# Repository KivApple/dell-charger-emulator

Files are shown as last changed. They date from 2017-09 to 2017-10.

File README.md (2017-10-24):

# dell-charger-emulator
Emulator of original Dell charger using ATTINY85

Power adapter for Dell laptops contains IC to determine adapter capabilities (watts, voltage, current).
If you connect an unoriginal adapter, the laptop refuses to charge the battery.
This project allows to use the cheap and small microcontroller ATTINY85 for emulating the answers
of the original adapter to the requests of the laptop.

You can configure adapter settings in the file eeprom-data.hex. This file contains EEPROM data in Intel Hex format.
Format of Dell charger identification shown below:

| Offset | Length | Content | Description |
|---|---|---|---|
| 0 | 4 | DELL | Manufacturer identifier  |
| 4 | 4 | 00AC | Adapter type |
| 8 | 3 | 045 | Watts (45W) |
| 11 | 3 | 195 | Tenths of a volt (19.5V) |
| 14 | 3 | 023 | Tenths of amps (2.3A) |
| 17 | 23 | CN0CDF577243865Q27F2A05 | Serial number |
| 40 | 2 | 0x3D 0x94 | CRC-16/ARC (LSB first) |

The description may not be entirely accurate. I'll be glad if you clarify.

You can use Python utility dell-charger-data-editor.py to easily change this values.

You must flash the EEPROM data together with the program code. Later you can only re-write EEPROM.

**Warning: do not mask the weak power adapter to a more powerful one. This can lead to hardware damage.**

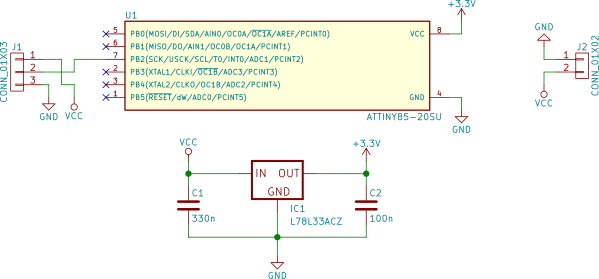
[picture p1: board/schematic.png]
Schematic


You need ATTINY25, ATTINY45 or ATTINY85 MCU (you may need to change compiler flags in Makefile) running at 8 MHz (the internal RC-oscillator is suitable, but if desired, you can use an external crystal - adjust the fuses accordingly). The Dell power adapter connector has three pins - GND, VOUT (19V) and ID. Connect the ID to the PB2 pin of the microcontroller. Also provide 3.3V power for MCU (you can use a simple linear regulator 78L33 to make the desired voltage from 19V).

## Reading and writing EEPROM

You can read and write EEPROM using dell-charger-data-editor.py (see console menu of this utility).

You need connect OneWire bus to any USB-UART adapter using simple schematic with diode:

    TXD --------|<|----*-------- ID
                       |
    RXD ----------------

    GND ------------------------ GND

**Warning: USB-UART adapter should use 3.3V or 5V logic levels. 12V levels will damage EEPROM IC.**

You can read by this utility both original EEPROM and emulated by AVR. You can write only emulated EEPROM.

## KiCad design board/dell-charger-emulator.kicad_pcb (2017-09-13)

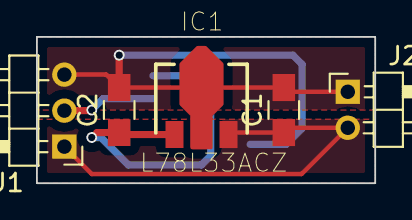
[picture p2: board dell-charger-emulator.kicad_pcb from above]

Board: 2 copper layers, 18.8 x 8.1 mm, 6 parts (1 on the bottom side), 4 nets.

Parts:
C1: 330n; C_0805_HandSoldering
C2: 100n; C_0805_HandSoldering
IC1: L78L33ACZ; SOT-89-3
J1: CONN_01X03; Pin_Header_Angled_1x03_Pitch2.00mm
J2: CONN_01X02; Pin_Header_Angled_1x02_Pitch2.00mm
U1: ATTINY85-20SU; SOIC-8_3.9x4.9mm_Pitch1.27mm

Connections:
+3V3: C2.1, IC1.1, U1.8
GND: C1.2, C2.2, IC1.2, J1.3, J2.1, U1.4
unnamed: J1.2, U1.7
VCC: C1.1, IC1.3, J1.1, J2.2

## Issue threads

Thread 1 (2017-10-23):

No Thorough Hardware Instructions

alxpettit, 2017-10-23:
It would be useful to see the wiring schematic you used for this project. Perhaps you could add it to README.md?

Edit: Also, I'm confused. Does this let us also program cheap Ebay knock offs to look like "genuine" Dell chargers? Your README.md instructs the user to connect to it to the "OneWire bus", but it's not exactly clear what that means. Some clear schematics of the use cases -- both when programming the chip, and when putting it into circuit, would be useful.

Edit 2: also, would this work on an 'duino? Lots more people have 'duinos, instead of Tiny85s lying around. I'd like to try this project before my Tiny85s and dev boards arrive.

KivApple, 2017-10-24:
I have wrote in README.md:

> You need ATTINY25, ATTINY45 or ATTINY85 MCU (you may need to change compiler flags in Makefile) running at 8 MHz (the internal RC-oscillator is suitable, but if desired, you can use an external crystal - adjust the fuses accordingly). The Dell power adapter connector has three pins - GND, VOUT (19V) and ID. Connect the ID to the PB2 pin of the microcontroller. Also provide 3.3V power for MCU (you can use a simple linear regulator 78L33 to make the desired voltage from 19V).

The connection scheme is present in the board directory in KiCad format, there is also a proposed printed circuit board. But since you ask, I added a picture to README.md.

The Python script is able to flash EEPROM through the 1wire only of the emulator on the AVR, it is not able to flash the real DS2502, because, first, it has an add-only memory, and secondly, it needs to supply the increased voltage at the right moment for programming. However, a script in Python is able to read the contents of both the emulator and the real memory chip. Of course, for the emulator to respond to the 1wire protocol, you need to download my firmware into it via any AVR programmer (for example, USBASP).

Perhaps this scheme will work on "large" microcontrollers like ATMEGA328 (used in many Arduino). In principle, all that the program needs is one external interrupt (INT0 usually) and one timer with one comparison channel. And a couple of kilobytes of ROM. However, AVR microcontrollers have some differences and most likely you will need a small edit of the sources to make everything work.

I used ATTINY, because in this way I could make a PCB of the smallest size and fit it into the plug of the power adapter. In addition, the ATTINY85 chip is cheaper than the ATMEGA328 chip.

alxpettit, 2017-10-28:
I've gotten arduino nano clones for as little as $3 per unit -- they are surprisingly cheap. I agree that they are definitely overkill for this project, and certainly wouldn't give you a great form factor, but general purpose programmable chips are overkill for a lot of their applications. I'd argue that the point of a programmable chip is to do lots of possible functions, some simple, and some really complex.

It only makes economical sense to make programmable chips that do simple things, because the less _unique_ things industry has to make, the cheaper it is to make them -- we can optimize via creating generic solutions and retooling them to every possible use case.

It's also good as a way to test an idea before you invest in more specialized hardware, I think. But Tiny85s are so cheap on Ebay, that I bought a couple of them just for testing on this project. I just think other people might not be willing to spend money experimentally, though -- and it's a shame, if they're barred from trying this project out because they don't have the hardware.

In my case, I can't really imagine a use for Tiny85s besides weird little things like this -- or just getting an LED to blink with a specific pattern, or doing some very very simple logic control... usually when I'm working with hardware, I'm working with fairly advanced robotics. (And furthermore, I'm normally a high level software gal. System administration, Python, that sort of thing. I rarely end up doing manual memory management, and the most low level thing I do is C++ coding on Arduinos, usually.)

So firmware-level things like this are out of my usual scope. I freely admit I could be talking out of my excretion hole here. And I totally respect if you don't want to put the effort in to translate it over to an arduino. :P

Oh, and sorry I didn't recognize the KiCad. I've never used it in my life before. The closest I've ever come is using a perfboard. Thank you for adding the PNG schematic!

TehseenHasan, 2020-06-27:
I made a complete tutorial: https://github.com/KivApple/dell-charger-emulator/issues/4#issuecomment-650623879

KivApple, 2020-06-27:
@alxpettit If anyone wants to add support for different AVR MCUs (such as ATMEGA328 which is used in Arduino Uno) feel free to create a pull request. You can easily upload plain C code into Arduino board. It is not required to use Arduino libraries when you are programming Arduino so you can write code which will be compatible both with ATTINY85 and ATMEGA328 (with few #ifdef's).

lgolebio, 2022-04-16:
Hi, I'm totaly noob at electronics and arduino. I have one question. Why it is not possbile to upload code to Digispark Attiny85 through built in USB port ?

Closed 2017-10-28.

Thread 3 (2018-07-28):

Possibility of using "arduino as ISP" to program attiny85 instead of 1wire?

alxpettit, 2018-07-28:
My current preferred setup for attiny programming consists of a board with an arduino programmed to function as a ISP, with a couple of additional components to prevent it from resetting to bootloader. The relevant wiring is essentially [this](https://create.arduino.cc/projecthub/arjun/programming-attiny85-with-arduino-uno-afb829?f=1). This is a very popular type of programmer I think, since a lot of people have and know where to get arduinos.

How would I use this project with my setup to program my attiny85?

hetii, 2019-01-02:
You can just compile this project by using its makefile and grab hex file to use with your arduino like programmer.
You can also change makefile and edit programmer type to match your programmer.

alxpettit, 2019-04-03:
Wow, this has been sitting here a long time!

For anyone curious, here's what I did to push the hex via my generic atmega328p board:
`avrdude -c arduino -P /dev/ttyUSB0 -p attiny85 -U flash:w:dell-charger-emulator.hex -b 19200`

It took a bit of poking around for me to figure out how to do this. Eventually I realized the easiest thing to do was simply try flashing via `Arduino as ISP` and see what options were sent. Turns out `-b 19200` was a prereq.

For anyone unfamiliar with `avrdude`:
`-c arduino` sets the programmer to `Arduino as ISP`, `-P` sets the port to the port of the arduino, and `-p` sets the AVR chip to compile for. `-U` is for operation.

Closed 2019-04-03.

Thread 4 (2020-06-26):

Can I use this code in Arduino Uno?

TehseenHasan, 2020-06-26:
Can I use this code and upload it into arduino? I have also same problem of the Dell charger.
and another question is that, if I use ATTINY85 then How Can I upload this complete code into ATTINY85?

TehseenHasan, 2020-06-27:
I figured it out. I used Arduino Uno as ISP Programmer to program the Digispark attiny85 module. Then I successfully uploaded the `dell-charger-emulator.hex` and `eeprom-data.hex` files into Attiny85 microcontroller by using the `avrduid` commands.

**This is the step by step tutorial I made for anyone who is doing the same thing:**

### Installing Arduino IDE and Attiny Microcontroller Boards:
Install the Arduino IDE. [Link to Download](https://www.arduino.cc/en/main/software)
Open the Arduino IDE.
By default Arduino IDE doesn't support ATtiny85 so we should add ATtiny boards to Arduino IDE.
Open File -> Preferences and in the Additional Boards Manager URLs and paste this url there: `https://raw.githubusercontent.com/damellis/attiny/ide-1.6.x-boards-manager/package_damellis_attiny_index.json`

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

After this is done open Tools -> Board -> Board Manager

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

After opening Board Manager scroll down the list where it says "attiny by Davis A. Mellis". Click on that and install it.

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

After installing now you would be able to see a new entry in the Board menu

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

### Connecting ATtiny85 with Arduino Uno
Now with all the above things ready we will start programming the attiny85. Connect the arduino uno to attiny85 using jumper wires as below:

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

Additional Hint (Optional): Add a 10uF capacitor between RESET and GND in arduino. This is to avoid arduino from being auto reset when we upload the program to attiny85. If you are using a electrolytic capacitor make sure the anode goes in GND of uno.

### Uploading program to ATtiny85
Now back to Arduino IDE. Select ATtiny under Tools -> Board. Then select ATtiny85 under Tools -> Processor. And select 8 MHz (internal) under Tools -> Clock.

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

Then make sure Arduino as ISP is selected under Tools -> Programmer

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

By default the ATtiny85 runs at 1MHz. To make it to run at 8MHz select Tools -> Burn Bootloader.

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

You will get the above message if burning bootloader was successful.

Now for testing purpose, open the Blink example from arduino examples and change the pin number from 13 to 0 and upload.

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

You can see the above message if everything was successful. Now we have upload the blink program to ATtiny85.
Now lets upload the actual dell-charger-emulator.hex` and `eeprom-data.hex` HEX files into the ATtiny85.

### Uploading dell-charger-emulator.hex` and `eeprom-data.hex` HEX in to ATtiny85

TehseenHasan, 2020-06-27:
a great benefit of using Digispark ATtiny85 Board is that it is **on-board voltage regulator**. So we can provide the 19.5 voltes of Dell Charger directly to the ATtiny85 Board on its `VCC pin`. So no need of external Voltage regulator on Digispark ATtiny85 Board.

tylerwight, 2022-04-20:
@TehseenHasan I actually got the same digispark attiny85s before coming here and realizing you did also. I was able to follow your directions and flash both hex files just fine. Thanks for your help! I also used avrdude to read the eeprom and it looks like the data I put there. Your post was very helpful and I appreciate it.

I am trying to get this working on 2 dell laptops that I got for free with no power adapter at all. Did the default hex work for you? The default specs for me are correct (45w, 19.5v, 2.3a) for me so I left them that way. Did you have to change your eeprom hex at all to get it working?

the laptops work fine they just don't charge the battery. The charger header has power ground and a single wire (I assume it's ID). They are older inspirons with i3 6xxx processors so I assume they are old enough the methods should still apply.

tylerwight, 2022-04-21:
I'm coming back here to provide an update to my last post:

The laptops I was testing with before were the exact same model, and they were 2-in-1s that flipped over, very tiny charge port that is not like the common dell barrel plug.

I did happen to have a different dell laptop that had the more standard barrel plug, and I also had an HP branded power adapter that fit exactly perfect including the center pin for data. So in order to test I took my programmed attiny85 as seen above and put it into the HP charger along the ID wire, and it works!

So it seems the dell Inspiron 11 3153's use a different type of charger that reports differently, so the code in the repository will not work for them. This is interesting though because all 3 laptops, the one the works and the 2 that don't, are all intel 6th gen processors, so they should be pretty close in age.

lgolebio, 2022-04-23:
I can confirm that on some Dell laptops communication with attiny85 doesn't work. It still shows unknown ac adapter. Maybe it is due to clock of attiny85 ?

lgolebio, 2022-04-24:
Hi. Just to inform anyone. I found a solution.

1.  Go to "tools => Library Manager"
2. In Filter search type "onewirehub" and install version 2.2.1
3. Go to "Examples => OnewWireHub => DS2502_DELLCHG"
4. Modify "**constexpr uint8_t pin_onewire   { 9 };**" to  "**constexpr uint8_t pin_onewire   { 2 };** "
5. The pin P2 of digispark is our onewire bus.
6. Upload the code to digispark
7. Works on all Dell laptops I have !

dainiusb, 2022-07-19:
I tried the one by sekyHC, this one and DS2502_DELLCHG example. Nothing seems to work with Dell Latitude D620.

dainiusb, 2022-07-20:
I'm measuring around 75 mV on the pin when chip isn't connected and on my oscilloscope I'm seeing low pulses of around 500 microseconds, is this normal?

dainiusb, 2022-07-20:
Nope, found a bad transistor.

dainiusb, 2022-07-21:
After repairing the laptop I tried the DS2502_DELLCHG example and it works!

FBMinis, 2023-01-22:
> Can I use this code and upload it into arduino? I have also same problem of the Dell charger. and another question is that, if I use Digispark ATTINY85 then How Can I upload this complete code into Digispark ATTINY85? 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
>
> I am using this Digispark attiny85 module and It can be programmed using Arduino IDE. Please help me that how can I program your code in this attiny85 module using Arduino IDE?

I followed your instructions and it worked perfectly.

I used the blue Digistump and in the Blink sketch I had to change LEDBuiltIN to 1.

When uploading the ArduinoISP sketch to the Uno, I used `#define USE_OLD_STYLE_WIRING` and used pins 10,11,12 and 13
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

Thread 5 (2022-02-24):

UART Schematic: Pullup needed?

mihaigalos, 2022-02-24:
Hi, not sure the schematic in its current form would work:
```
TXD --------|<|----*-------- ID
                   |
RXD ----------------

GND ------------------------ GND
```
Seems `TXD` is at least missing a pullup on the anode (assuming the diode polarity is correct), since when you want to send, you would drive the pin low and open the diode:

```
                        VCC
                        _|_
                       |  |
                       |__|
                        |
TXD --------|<|----*----*--- ID
                   |
RXD ----------------

GND ------------------------ GND
```

lgolebio, 2022-04-21:
Yes. I can confirm that pullup resistor is needed 4,7Kohm. Without it it reads data but incorrect.

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

rahmajayagrs, 2022-09-16:
read correct , but write fail
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

mihaigalos, 2022-09-16:
@rahmajayagrs, so the conclusion is that it only works without the pullup?

rahmajayagrs, 2022-09-16:
with or without pullUp still can read but can't write

mihaigalos, 2022-09-19:
@rahmajayagrs the value of the pullup is important, as is the maximum baud rate.
Try using a lower baudrate (i.e. `9600`) and a resistor value of `4.7K`.

Also, double check your wiring.

arekm, 2024-07-10:
Here I was able to read EEPROM contents of original 130W Dell charger and also of emulated EEPROM but only with 4.7k pullup. No speed change was needed. My USB adapter had FTDI chip in it.

Didn't try to reprogram emulated EEPROM that way since Dell XPS 9530 I was testing recognized emulated charger properly. Programming was done in place on digispark attiny85 board, using TL866II Plus with SOIC8 clip. Fuse bits set the same way as in project Makefile.

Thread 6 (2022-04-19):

Outdated python script

lgolebio, 2022-04-19:
Hi
It looks like dell-charger-data-editor.py no longer works on ubuntu 20.04.

` File "dell-charger-data-editor_backup.py", line 192`
    `print('%02x ' % byte, end='', flush=True)`
`                                            ^`

tylerwight, 2022-04-20:
python 2 and 3 have different print syntax. Could this be the difference? I ran the python script today and it ran fine.

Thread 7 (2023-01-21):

How should I edit the hex file to emulate a 65W charger?

FBMinis, 2023-01-21:
I have the attiny85 ready to receive the hex and all the hardware ready. My laptop is a Dell E4300 and it needs a 65W power supply.

I have the power supply from a Toshiba, 19V and 6.32A

Could someone please share the hex modified so I can emulate a 65W power supply?

Thank you

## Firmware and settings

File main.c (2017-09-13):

#include <stddef.h>
#include <avr/io.h>
#include <avr/interrupt.h>
#include <avr/sleep.h>
#include <avr/pgmspace.h>
#include <avr/eeprom.h>
#include <util/delay.h>
#include "crc8.h"

#define EEPROM_DATA_LENGTH 128

static const uint8_t ow_address[8] PROGMEM = { 0x09, 0x52, 0x8D, 0xED, 0x65, 0x00, 0x00, 0xEF };
static const uint8_t default_eeprom_data[EEPROM_DATA_LENGTH] PROGMEM = {
	'D', 'E', 'L', 'L', '0', '0', 'A', 'C', '0', '4', '5', '1', '9', '5', '0', '2',
	'3', 'C', 'N', '0', 'C', 'D', 'F', '5', '7', '7', '2', '4', '3', '8', '6', '5',
	'Q', '2', '7', 'F', '2', 'A', '0', '5', '=', 0x94, 0xFF, 0xFF, 0xFF, 0xFF, 0xFF, 0xFF,
	0xFF, 0xFF, 0xFF, 0xFF, 0xFF, 0xFF, 0xFF, 0xFF, 0xFF, 0xFF, 0xFF, 0xFF, 0xFF, 0xFF, 0xFF, 0xFF,
	0xFF, 0xFF, 0xFF, 0xFF, 0xFF, 0xFF, 0xFF, 0xFF, 0xFF, 0xFF, 0xFF, 0xFF, 0xFF, 0xFF, 0xFF, 0xFF,
	0xFF, 0xFF, 0xFF, 0xFF, 0xFF, 0xFF, 0xFF, 0xFF, 0xFF, 0xFF, 0xFF, 0xFF, 0xFF, 0xFF, 0xFF, 0xFF,
	0xFF, 0xFF, 0xFF, 0xFF, 0xFF, 0xFF, 0xFF, 0xFF, 0xFF, 0xFF, 0xFF, 0xFF, 0xFF, 0xFF, 0xFF, 0xFF,
	0xFF, 0xFF, 0xFF, 0xFF, 0xFF, 0xFF, 0xFF, 0xFF, 0xFF, 0xFF, 0xFF, 0xFF, 0xFF, 0xFF, 0xFF, 0xFF
};

enum {
	OW_STATE_IDLE,
	OW_STATE_RESET,
	OW_STATE_PRESENCE,
	OW_STATE_RX,
	OW_STATE_TX
};

enum {
	OW_DATA_SOURCE_RAM,
	OW_DATA_SOURCE_ROM,
	OW_DATA_SOURCE_EEPROM
};

static struct {
	uint8_t state;
	uint8_t bit_state;
	uint8_t current_byte;
	uint8_t current_bit;
	uint8_t current_value;
	union {
		const uint8_t *tx_buffer;
		uint8_t *rx_buffer;
	};
	uint8_t buffer_size;
	uint8_t buffer_source;
	void (*callback)(void);
	uint8_t command;
	uint8_t selected;
	uint8_t pull_low_next;
	uint8_t arg_buffer[8];
} ow = {
	.state = OW_STATE_IDLE,
	.bit_state = 1
};

#define OW_RELEASE() do { DDRB &= ~_BV(PB2); PORTB |= _BV(PB2); } while (0)
#define OW_PULL_LOW() do { PORTB &= ~_BV(PB2); DDRB |= _BV(PB2); } while (0)

static inline void ow_start_timer(void) {
	TCNT0 = 0;
#if F_CPU == 1000000
	TCCR0B = _BV(CS00);
#elif (F_CPU >= 8000000) && (F_CPU <= 9000000)
	TCCR0B = _BV(CS01);
#else
#error F_CPU should be 1 MHz or 8..9 MHz
#endif
}

static inline void ow_rx(uint8_t *buffer, uint8_t count, void (*callback)(void)) {
	ow.state = OW_STATE_RX;
	ow.rx_buffer = buffer;
	ow.buffer_size = count;
	ow.callback = callback;
	ow.current_byte = 0;
	ow.current_bit = 0;
	ow.current_value = 0;
}

static inline void ow_fetch_current_byte_from_buffer() {
	switch (ow.buffer_source) {
		case OW_DATA_SOURCE_RAM:
			ow.current_value = ow.tx_buffer[ow.current_byte];
			break;
		case OW_DATA_SOURCE_ROM:
			ow.current_value = pgm_read_byte(ow.tx_buffer + ow.current_byte);
			break;
		case OW_DATA_SOURCE_EEPROM:
			ow.current_value = eeprom_read_byte(ow.tx_buffer + ow.current_byte);
			break;
	}
}

static inline void ow_tx(const uint8_t *buffer, uint8_t count, uint8_t source, void (*callback)(void)) {
	ow.state = OW_STATE_TX;
	ow.tx_buffer = buffer;
	ow.buffer_size = count;
	ow.buffer_source = source;
	ow.callback = callback;
	ow.current_byte = 0;
	ow.current_bit = 0;
	ow_fetch_current_byte_from_buffer();
	ow.pull_low_next = !(ow.current_value & 1);
}

static void ow_read_real_mem(void) {
	uint16_t offset = (((uint16_t) ow.arg_buffer[1]) << 8) | ow.arg_buffer[0];
	uint8_t max_len = EEPROM_DATA_LENGTH - offset;
	const uint8_t *base = (const uint8_t*) offset;
	ow_tx(base, max_len, OW_DATA_SOURCE_EEPROM, NULL);
}

static void ow_read_mem(void) {
	uint8_t tmp[] = { ow.command, ow.arg_buffer[0], ow.arg_buffer[1] };
	ow.arg_buffer[2] = Crc8(tmp, sizeof(tmp));
	ow_tx(ow.arg_buffer + 2, 1, OW_DATA_SOURCE_RAM, ow_read_real_mem);
}

static void ow_write_real_mem(void) {
	uint16_t offset = (((uint16_t) ow.arg_buffer[1]) << 8) | ow.arg_buffer[0];
	uint8_t data = ow.arg_buffer[2];
	uint8_t *base = (uint8_t*) offset;
	eeprom_write_byte(base, data);
}

static void ow_write_mem(void) {
	uint8_t tmp[] = { ow.command, ow.arg_buffer[0], ow.arg_buffer[1], ow.arg_buffer[2] };
	ow.arg_buffer[3] = Crc8(tmp, sizeof(tmp));
	ow_tx(ow.arg_buffer + 2, 1, OW_DATA_SOURCE_RAM, ow_write_real_mem);
}

static void ow_command_received(void) {
	switch (ow.command) {
		case 0x33: // READ ROM
			ow_tx(ow_address, 8, OW_DATA_SOURCE_ROM, NULL);
			break;
		case 0xCC: // SKIP ROM
			ow.selected = 1;
			ow_rx(&(ow.command), sizeof(ow.command), ow_command_received);
			break;
		case 0xF0: // READ MEM
			if (ow.selected) {
				ow_rx(ow.arg_buffer, 2, ow_read_mem);
			}
			break;
		case 0x0F: // WRITE MEM
			if (ow.selected) {
				ow_rx(ow.arg_buffer, 3, ow_write_mem);
			}
	}
}

static void ow_bit_change(uint8_t bit) {
	//bit ? (PORTB |= _BV(PB1)) : (PORTB &= ~_BV(PB1));
	switch (ow.state) {
		case OW_STATE_RESET:
			if (bit) {
				ow.state = OW_STATE_PRESENCE;
				OW_PULL_LOW();
				OCR0A = 200;
			}
			break;
		case OW_STATE_RX:
			if (!bit) {
				_delay_us(10);
				uint8_t cur_bit = ow.current_bit;
				if (PINB & _BV(PB2)) {
					ow.current_value |= _BV(cur_bit);
				}
				cur_bit++;
				if (cur_bit == 8) {
					uint8_t cur_byte = ow.current_byte;
					ow.rx_buffer[cur_byte++] = ow.current_value;
					ow.current_value = 0;
					cur_bit = 0;
					if (cur_byte == ow.buffer_size) {
						ow.state = OW_STATE_IDLE;
					}
					ow.current_byte = cur_byte;
				}
				ow.current_bit = cur_bit;
				if (ow.state == OW_STATE_IDLE) {
					if (ow.callback) {
						ow.callback();
					}
				}
			}
			break;
		case OW_STATE_TX:
			if (!bit) {
				_delay_us(30);
				uint8_t cur_bit = ow.current_bit;
				cur_bit++;
				if (cur_bit == 8) {
					uint8_t cur_byte = ow.current_byte;
					cur_byte++;
					cur_bit = 0;
					if (cur_byte == ow.buffer_size) {
						ow.state = OW_STATE_IDLE;
					} else {
						ow.current_byte = cur_byte;
						ow_fetch_current_byte_from_buffer();
					}
				}
				if (ow.state != OW_STATE_IDLE) {
					ow.pull_low_next = !(ow.current_value & _BV(cur_bit));
				}
				ow.current_bit = cur_bit;
				OW_RELEASE();
				if (ow.state == OW_STATE_IDLE) {
					if (ow.callback) {
						ow.callback();
					}
				}
			}
			break;
	}
	if (!bit) {
		ow_start_timer();
	} else {
		_delay_us(10);
	}
}

ISR(INT0_vect) {
	uint8_t bit = ow.bit_state;
	do {
		GIFR = _BV(INTF0);
		bit = !bit;
		if (!bit && ow.pull_low_next) {
			OW_PULL_LOW();
			ow.pull_low_next = 0;
		}
		ow_bit_change(bit);
	} while (GIFR & _BV(INTF0));
	ow.bit_state = (PINB & _BV(PB2)) ? 1 : 0;
}

ISR(TIMER0_OVF_vect) {
	TCCR0B = 0;
	TIFR = _BV(OCF0A);
	if (!ow.bit_state) {
		ow.state = OW_STATE_RESET;
		ow.selected = 0;
	}
}

ISR(TIMER0_COMPA_vect) {
	switch (ow.state) {
		case OW_STATE_PRESENCE:
			OW_RELEASE();
			ow_rx(&ow.command, sizeof(ow.command), ow_command_received);
			break;
	}
}

int main(void) {
	// Disable analog comparator
	ACSR |= _BV(ACD);
	// Disable ADC, TIM1 and USI
	PRR |= _BV(PRADC) | _BV(PRUSI) | _BV(PRTIM1);
	// All pins: Input pullup
	DDRB = 0;
	PORTB = 0xFF;
	// Check EEPROM and load default values if needed
	OW_PULL_LOW();	
	if (eeprom_read_byte((const uint8_t*) 0) == 0xFF) {
		for (uint8_t i = 0; i < EEPROM_DATA_LENGTH; i++) {
			eeprom_write_byte(((uint8_t*) 0) + i, pgm_read_byte(default_eeprom_data + i));
		}
	} else {
		_delay_us(10);
	}
	OW_RELEASE();
	// TIM0: overflow and compare A interrupts
	TIMSK |= _BV(TOIE0) | _BV(OCIE0A);
	OCR0A = 0;
	// INT0: Any change
	MCUCR = (MCUCR | _BV(ISC00)) & ~_BV(ISC01);
	GIMSK |= _BV(INT0);
	// Read current line state
	GIFR = _BV(INTF0);
	ow.bit_state = (PINB & _BV(PB2)) ? 1 : 0;
	// Enable interrupts
	sei();
	// Main loop
	set_sleep_mode(SLEEP_MODE_IDLE);
	while (1) {
		sleep_bod_disable();
		sleep_mode();
	}
}

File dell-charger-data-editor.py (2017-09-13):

#!/usr/bin/env python 
import sys, math

if len(sys.argv) >= 2:
	filename = sys.argv[1]
else:
	filename = 'eeprom-data.hex'

EEPROM_SIZE = 128
try:
	with open(filename) as f:
		data = [0xFF] * EEPROM_SIZE
		for l in f:
			if l[0] != ':':
				raise Exception('Invalid input file format')
			length = int(l[1:1 + 2], 16)
			offset = int(l[3:3 + 4], 16)
			t = int(l[7:7 + 2], 16)			
			if t == 1:
				break
			elif t == 0:
				i = 0
				while i < length:
					j = 9 + i * 2
					byte = int(l[j:j + 2], 16)
					data[offset + i] = byte
					i += 1
except Exception as e:
	print('Warning: %s' % str(e))
	data = [ord(char) for char in 'DELL00AC045195023CN0CDF577243865Q27F2A05'] + [0x3D, 0x94] + [0xFF] * (EEPROM_SIZE - 42)

def get_manufacturer():
	try:
		return ''.join([chr(code if (((code >= ord('0')) and (code <= ord('9'))) or ((code >= ord('A')) and (code <= ord('Z')))) else None) for code in data[0:4]])
	except:
		print('Warning: invalid manufacturer')
		return '????'

def get_adapter_type():
	try:
		return ''.join([chr(code if (((code >= ord('0')) and (code <= ord('9'))) or ((code >= ord('A')) and (code <= ord('Z')))) else None) for code in data[4:8]])
	except:
		print('Warning: invalid adapter type')
		return '????'

def get_watts():
	try:
		return int(''.join(chr(code) for code in data[8:8 + 3]))
	except:
		print('Warning: invalid wattage value')
		return 0

def get_volts():
	try:
		return int(''.join([chr(code) for code in data[11:11 + 3]])) / 10
	except:
		print('Warning: invalid voltage value')
		return 0

def get_amps():
	try:
		return int(''.join([chr(code) for code in data[14:14 + 3]])) / 10
	except:
		print('Warning: invalid amperage value')
		return 0.0

def get_serial_number():
	try:
		return ''.join([chr(code if (((code >= ord('0')) and (code <= ord('9'))) or ((code >= ord('A')) and (code <= ord('Z')))) else None) for code in data[17:17 + 23]])
	except:
		print('Warning: invalid serial number')
		return '???????????????????????'

def set_data(offset, s):
	for char in s:
		data[offset] = ord(char)
		offset += 1

def save_data(filename):
	crc = 0
	for offset in range(0, 40):
		byte = data[offset]
		crc ^= byte
		for i in range(0, 8):
			if crc & 1:
				crc = crc = (crc >> 1) ^ 0xA001;
			else:
				crc >>= 1
	crc_l = crc & 0xFF
	crc_h = crc >> 8
	if (crc_l != data[40]) or (crc_h != data[41]):
		print('Info: checksum changed. Updating...')
		data[40] = crc_l
		data[41] = crc_h
	with open(filename, 'w') as f:
		offset = 0
		while offset < EEPROM_SIZE:
			chunk = data[offset:offset + 16]
			chunk = [len(chunk), offset >> 8, offset & 0xFF, 0] + chunk
			checksum = 0
			for byte in chunk:
				checksum = (checksum + byte) & 0xFF
			checksum = (0x100 - checksum) & 0xFF
			f.write((':%s%02x\n' % (''.join(['%02x' % code for code in chunk]), checksum)).upper())
			offset += 16
		f.write(':00000001FF\n')

def open_serial_port():
	try:
		import serial
		import serial.tools.list_ports
	except Exception as e:
		print(str(e))
		print('Please install pyserial to use this functional!')
		return
	while True:
		ports = serial.tools.list_ports.comports()
		print(' [0] Return to main menu')
		print(' [1] Enter custom serial port name')	
		i = 2
		for port in ports:
			print(' [%i] %s' % (i, port))
			i += 1
		try:
			j = int(input('Select option [0-%i]: ' % (i - 1)))
			if (j < 0) or (j >= i):
				continue
			if j == 0:
				return
			try:
				if j == 1:
					port = input('Enter serial port name (e. g. /dev/ttyUSB0, COM1): ')
					return serial.Serial(port)
				else:
					port = ports[j - 2]
					return serial.Serial(port[0])
			except Exception as e:
				print('Error: %s' % str(e))
		except Exception:
			continue

def ow_reset(port):
	port.timeout = 1
	port.bytesize = 8
	port.parity = 'N'
	port.stopbits = 1
	port.rtscts = 0
	port.xonxoff = 0
	port.baudrate = 9600
	port.write(b'\xF0')
	response = port.read(1)
	port.baudrate = 115200
	if len(response) != 1:
		print('Warning: Timeout! Did you forgot to connect diode RX -|>|- TX?')
	return (len(response) == 1) and (response[0] < 0xF0)

def ow_write(port, byte):
	for i in range(0, 8):
		value = b'\xFF' if byte & (1 << i) else b'\x00'
		port.write(value)
		response = port.read(1)
		if (len(response) != 1) or (response[0] != value[0]):
			return False
	return True

def ow_write_bytes(port, bytes):
	for byte in bytes:
		if not ow_write(port, byte):
			return False
	return True

def ow_read(port):
	value = 0
	for i in range(0, 8):
		port.write(b'\xFF')
		response = port.read(1)
		if len(response) != 1:
			return None
		if response[0] > 0xFE:
			value |= 1 << i
	return value

def ow_read_bytes(port, count):
	bytes = list()
	offset = 0
	while offset < count:
		byte = ow_read(port)
		if byte is None:
			return None
		bytes.append(byte)
		if (offset % 16) != 15:
			print('%02x ' % byte, end='', flush=True)
		else:
			print('%02x' % byte)
		offset += 1
	print('')
	return bytes

def read_eeprom():
	global data
	port = open_serial_port()
	if not port:
		return
	with port as port:
		if not ow_reset(port):
			print('Failed to issue OneWire reset!')
			return
		if not ow_write_bytes(port, b'\xCC\xF0\x00\x00'):
			print('Failed to send READ MEM command!')
			return
		print('Reading EEPROM...')
		bytes = ow_read_bytes(port, 130)
		if bytes is None:
			print('Failed to read data!')
		data = bytes[1:-1]
		print('Done')

def write_eeprom():
	port = open_serial_port()
	if not port:
		return
	with port as port:
		print('Writing...')
		offset = 0
		while offset < len(data):
			byte = data[offset]
			if not ow_reset(port):
				print('Failed to issue OneWire reset (offset = %i)!' % offset)
				return
			if not ow_write_bytes(port, b'\xCC\x0F' + bytes([offset & 0xFF, offset >> 8, byte])):
				print('Failed to issue WRITE MEM command (offset = %i)!' % offset)
				return
			response = ow_read(port)
			if response is None:
				print('Write failed (offset = %i)!' % offset)
			if (offset % 16) != 15:
				print('%02x ' % response, end='', flush=True)
			else:
				print('%02x' % response)
			offset += 1
		print('')
		print('Done')

def print_menu():
	m = get_manufacturer()
	t = get_adapter_type()
	w = get_watts()
	v = get_volts()
	a = get_amps()
	sn = get_serial_number()
	print(' [0] Manufacturer  : %s' % m)
	print(' [1] Adapter type  : %s' % t)
	print(' [2] Watts         : %s' % w)
	print(' [3] Volts         : %s' % v)
	print(' [4] Amps          : %s' % a)
	print(' [5] Serial number : %s' % sn)
	print(' [6] Save changes and exit')
	print(' [7] Exit without saving changes')
	print(' [8] Read EEPROM data via 1wire')
	print(' [9] Write EEPROM data via 1wire')
	while True:
		try:
			return int(input('Select option [0-9]: '))
		except Exception:
			continue
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

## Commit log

2017-09-10 Move address to PROGMEM Small fix
    [main.c]
2017-09-10 Disable USI for reduce current
2017-09-10 Switch all pins to input pullup state on startu[ Fuses
2017-09-11 Added schematic and PCB layout
    [dell-charger-emulator.kicad_pcb, dell-charger-emulator.sch]
2017-09-13 Update board
    [dell-charger-emulator.kicad_pcb, dell-charger-emulator.sch]
2017-09-13 Move charger data to EEPROM Added Python utility to edit EEPROM
